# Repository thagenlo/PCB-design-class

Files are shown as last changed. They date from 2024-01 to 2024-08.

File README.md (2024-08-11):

# PCB-design-class
2.S975 KiCAD repo

**Multimeter Project**
multimeter 3D PCB 1
Screenshot 2024-08-11 at 10 22 29 AM
Screenshot 2024-08-11 at 10 22 42 AM
Screenshot 2024-08-11 at 10 22 52 AM
Screenshot 2024-08-11 at 10 23 01 AM
Screenshot 2024-08-11 at 10 23 08 AM

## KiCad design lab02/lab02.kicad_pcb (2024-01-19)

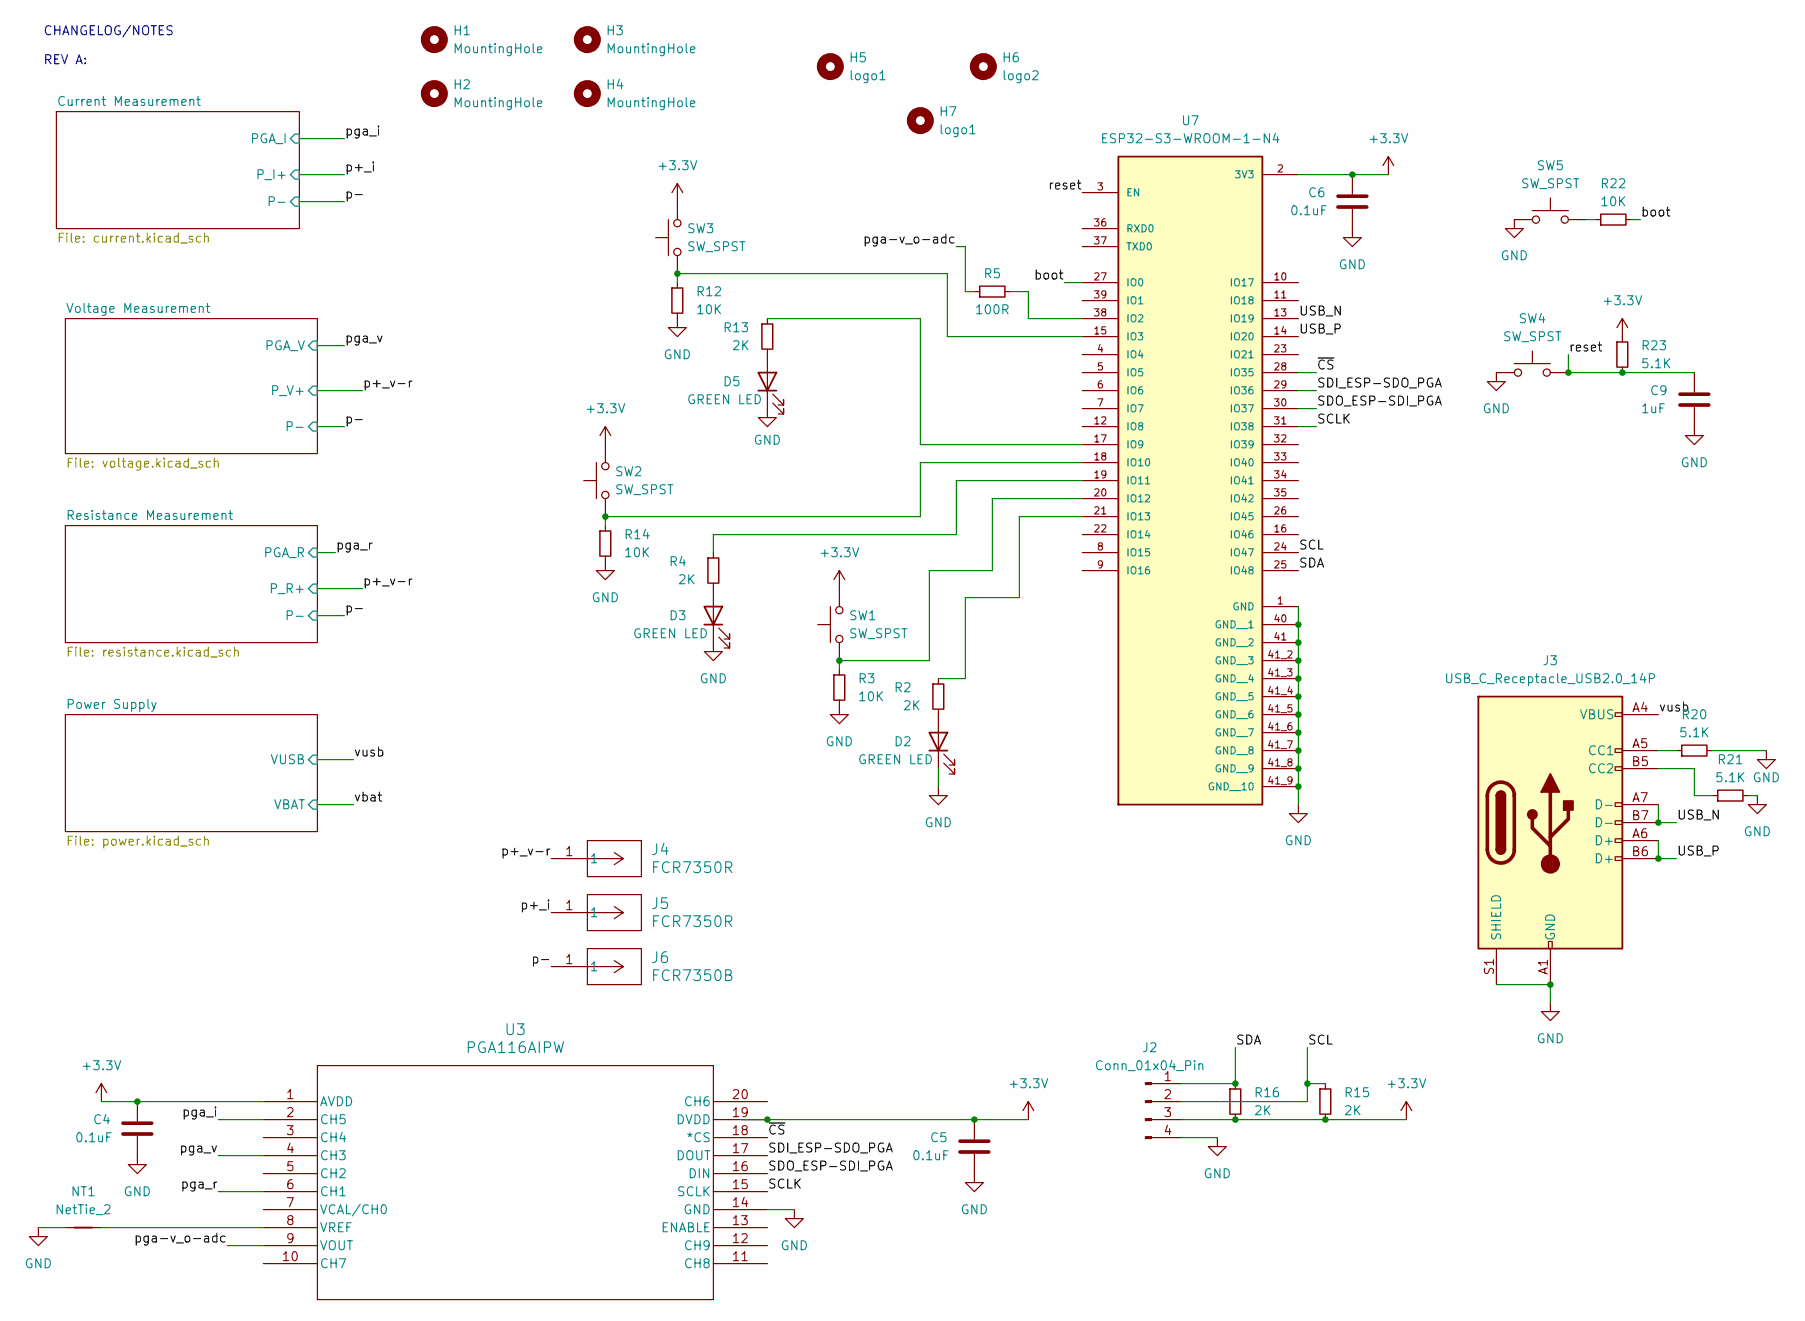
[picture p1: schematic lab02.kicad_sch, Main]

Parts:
C4, C5, C6: 0.1uF; C_0603_1608Metric
C9: 1uF; C_0603_1608Metric
D2, D3, D5: GREEN LED; LED_0603_1608Metric_Pad1.05x0.95mm_HandSolder; MPN LTST-C190GKT; Digikey PN 160-1183-1-ND
H1, H2, H3, H4: MountingHole; MountingHole_2.5mm
H5: logo1; EdgertonLogo
H6: logo2; EECSLogo
H7: logo1; MechE
J2: Conn_01x04_Pin; PPTC041LFBN-RC; MPN PPTC041LFBN-RC; Digikey PN S7002-ND
J3: USB_C_Receptacle_USB2.0_14P; USB_C_Receptacle_GCT_USB4085; MPN USB4085-GF-A; Digikey PN 2073-USB4085-GF-ACT-ND
J4, J5: FCR7350R; CONN1_FCR7350R_CLF; MPN FCR7350R; Digikey PN 4654-FCR7350R-ND
J6: FCR7350B; CONN1_FCR7350R_CLF; MPN FCR7350B; Digikey PN 4654-FCR7350B-ND
NT1: NetTie_2; NetTie-2_SMD_Pad0.5mm
R2, R4, R13, R15, R16: 2K; R_0603_1608Metric
R3, R12, R14, R22: 10K; R_0603_1608Metric
R5: 100R; R_0603_1608Metric
R20, R21, R23: 5.1K; R_0603_1608Metric
SW1, SW2, SW3, SW4, SW5: SW_SPST; SWITCH_FSMSM_TYC; MPN FSMSM; Digikey PN 450-1140-ND
U3: PGA116AIPW; PGA116AIPWR; MPN PGA116AIPWR; Digikey PN 296-23772-1-ND
U7: ESP32-S3-WROOM-1-N4; ESP32-S3-WROOM-1; PARTREV v1.0; Digikey PN 1965-ESP32-S3-WROOM-1-N4CT-ND

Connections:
+3.3V: C4.1, C5.1, C6.1, J2.3, R15.2, R16.2, R23.1, SW1.2, SW2.2, SW3.2, U3.1 (AVDD), U3.19 (DVDD), U7.2 (3V3); also elsewhere on the board
/SCL: J2.2, R15.1, U7.24 (IO47)
/SCLK: U3.15 (SCLK), U7.31 (IO38)
/SDA: J2.1, R16.1, U7.25 (IO48)
/SDI_ESP-SDO_PGA: U3.17 (DOUT), U7.29 (IO36)
/SDO_ESP-SDI_PGA: U3.16 (DIN), U7.30 (IO37)
/USB_N: J3.A7 (D-), J3.B7 (D-), U7.13 (IO19)
/USB_P: J3.A6 (D+), J3.B6 (D+), U7.14 (IO20)
/boot: R22.2, U7.27 (IO0)
/p+_i: J5.1; also elsewhere on the board
/p+_v-r: J4.1; also elsewhere on the board
/pga-v_o-adc: R5.1, U3.9 (VOUT)
/pga_i: U3.2 (CH5); also elsewhere on the board
/pga_r: U3.6 (CH1); also elsewhere on the board
/pga_v: U3.4 (CH3); also elsewhere on the board
/reset: C9.1, R23.2, SW4.2, U7.3 (EN)
/vusb: J3.A4 (VBUS), J3.A9 (VBUS), J3.B4 (VBUS), J3.B9 (VBUS); also elsewhere on the board
/~CS: U3.18 (*CS), U7.28 (IO35)
GND: C4.2, C5.2, C6.2, C9.2, D2.1 (K), D3.1 (K), D5.1 (K), J2.4, J3.A1 (GND), J3.A12 (GND), J3.B1 (GND), J3.B12 (GND), J3.S1 (SHIELD), J6.1, NT1.1, R3.2, R12.2, R14.2, R20.2, R21.2, SW4.1, SW5.1, U3.14 (GND), U7.1 (GND), U7.40 (GND__1), U7.41 (GND__2), U7.41_2 (GND__3), U7.41_3 (GND__4), U7.41_4 (GND__5), U7.41_5 (GND__6), U7.41_6 (GND__7), U7.41_7 (GND__8), U7.41_8 (GND__9), U7.41_9 (GND__10); also elsewhere on the board
unnamed: D2.2 (A), R2.2
unnamed: D3.2 (A), R4.2
unnamed: D5.2 (A), R13.2
unnamed: J3.A5 (CC1), R20.1
unnamed: J3.B5 (CC2), R21.1
unnamed: R22.1, SW5.2
unnamed: NT1.2, U3.8 (VREF)
unnamed: R5.2, U7.38 (IO2)
unnamed: R12.1, SW3.1, U7.15 (IO3)
unnamed: R13.1, U7.17 (IO9)
unnamed: R14.1, SW2.1, U7.18 (IO10)
unnamed: R4.1, U7.19 (IO11)
unnamed: R3.1, SW1.1, U7.20 (IO12)
unnamed: R2.1, U7.21 (IO13)

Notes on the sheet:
CHANGELOG/NOTES REV A:

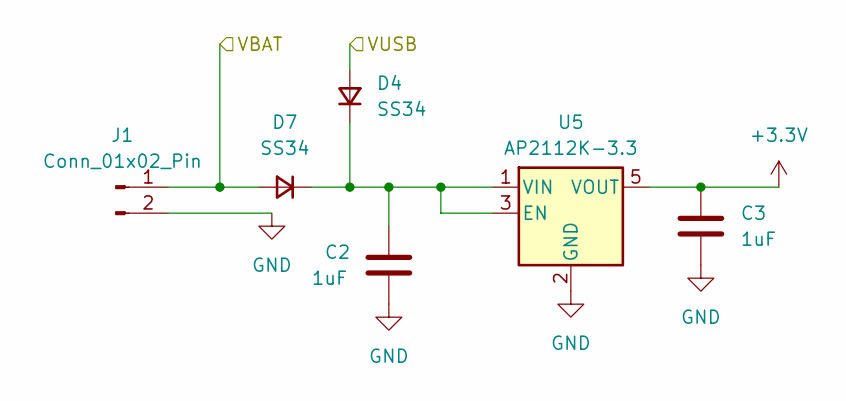
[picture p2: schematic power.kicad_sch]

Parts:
C2, C3: 1uF; C_0603_1608Metric
D4, D7: SS34; D_SMC
J1: Conn_01x02_Pin; JST_B2B-XH-A; MPN B2B-XH-A; Digikey PN 455-B2B-XH-A-ND
U5: AP2112K-3.3; SOT-23-5; MPN AP2112K-3.3TRG1; Digikey PN AP2112K-3.3TRG1DICT-ND

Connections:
+3.3V: C3.1, U5.5 (VOUT); also elsewhere on the board
/vbat: D7.2 (A), J1.1
/vusb: D4.2 (A); also elsewhere on the board
GND: C2.2, C3.2, J1.2, U5.2 (GND); also elsewhere on the board
unnamed: C2.1, D4.1 (K), D7.1 (K), U5.1 (VIN), U5.3 (EN)

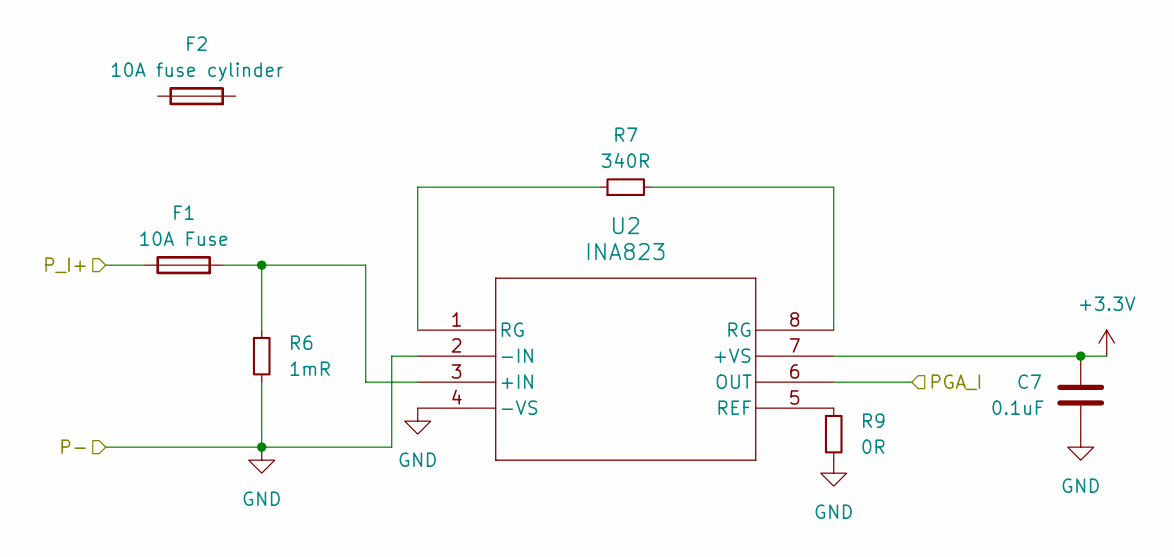
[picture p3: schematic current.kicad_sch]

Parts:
C7: 0.1uF; C_0603_1608Metric
F1: 10A Fuse; FUSE_31.8221_SCH; MPN 0031.8221; Digikey PN 486-1260-ND
F2: 10A fuse cylinder; MPN 7010.3530; Digikey PN 486-1865-ND
R6: 1mR; CSNL1206FT1L00; MPN CSNL1206FT1L00; Digikey PN CSNL1206FT1L00CT-ND
R7: 340R; R_0603_1608Metric
R9: 0R; R_0603_1608Metric
U2: INA823; SOIC-8_3.9x4.9mm_P1.27mm; MPN INA823DT; Digikey PN 296-INA823DTCT-ND

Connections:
+3.3V: C7.1, U2.7 (+VS); also elsewhere on the board
/p+_i: F1.1; also elsewhere on the board
/pga_i: U2.6 (OUT); also elsewhere on the board
GND: C7.2, R6.2, R9.2, U2.2 (-IN), U2.4 (-VS); also elsewhere on the board
unnamed: R7.1, U2.1 (RG)
unnamed: R7.2, U2.8 (RG)
unnamed: F1.2, R6.1, U2.3 (+IN)
unnamed: R9.1, U2.5 (REF)

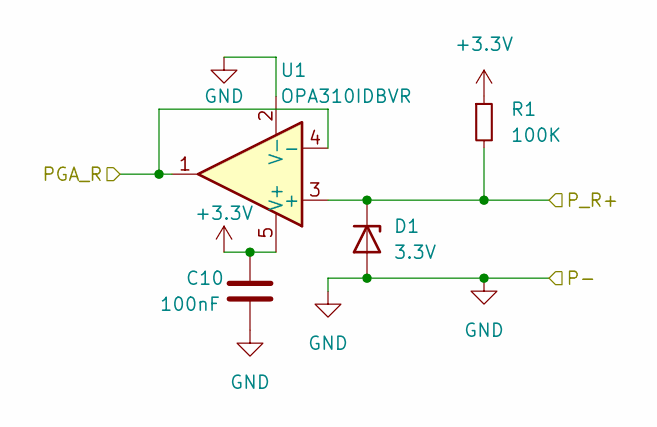
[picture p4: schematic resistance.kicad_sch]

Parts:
C10: 100nF; C_0603_1608Metric
D1: 3.3V; MMSZ4684T1G; MPN MMSZ4684T1G; Digikey PN MMSZ4684T1GOSCT-ND
R1: 100K; R_0603_1608Metric
U1: OPA310IDBVR; MPN OPA310IDBVR; Digikey PN 296-OPA310IDBVRCT-ND

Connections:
+3.3V: C10.1, R1.1, U1.5 (V+); also elsewhere on the board
/p+_v-r: D1.1 (K), R1.2, U1.3 (+); also elsewhere on the board
/pga_r: U1.1, U1.4 (-); also elsewhere on the board
GND: C10.2, D1.2 (A), U1.2 (V-); also elsewhere on the board

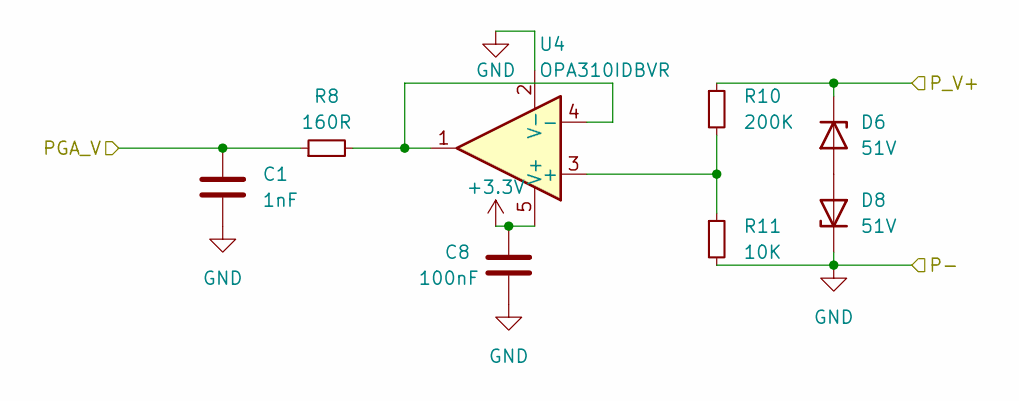
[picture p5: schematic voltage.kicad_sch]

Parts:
C1: 1nF; C_0603_1608Metric
C8: 100nF; C_0603_1608Metric
D6, D8: 51V; BZT52C51-7-F; MPN BZT52C51-7-F; Digikey PN BZT52C51-FDICT-ND
R8: 160R; R_0603_1608Metric
R10: 200K; R_0603_1608Metric
R11: 10K; R_0603_1608Metric
U4: OPA310IDBVR; MPN OPA310IDBVR; Digikey PN 296-OPA310IDBVRCT-ND

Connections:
+3.3V: C8.1, U4.5 (V+); also elsewhere on the board
/p+_v-r: D6.1 (K), R10.1; also elsewhere on the board
/pga_v: C1.1, R8.1; also elsewhere on the board
GND: C1.2, C8.2, D8.1 (K), R11.2, U4.2 (V-); also elsewhere on the board
unnamed: D6.2 (A), D8.2 (A)
unnamed: R10.2, R11.1, U4.3 (+)
unnamed: R8.2, U4.1, U4.4 (-)

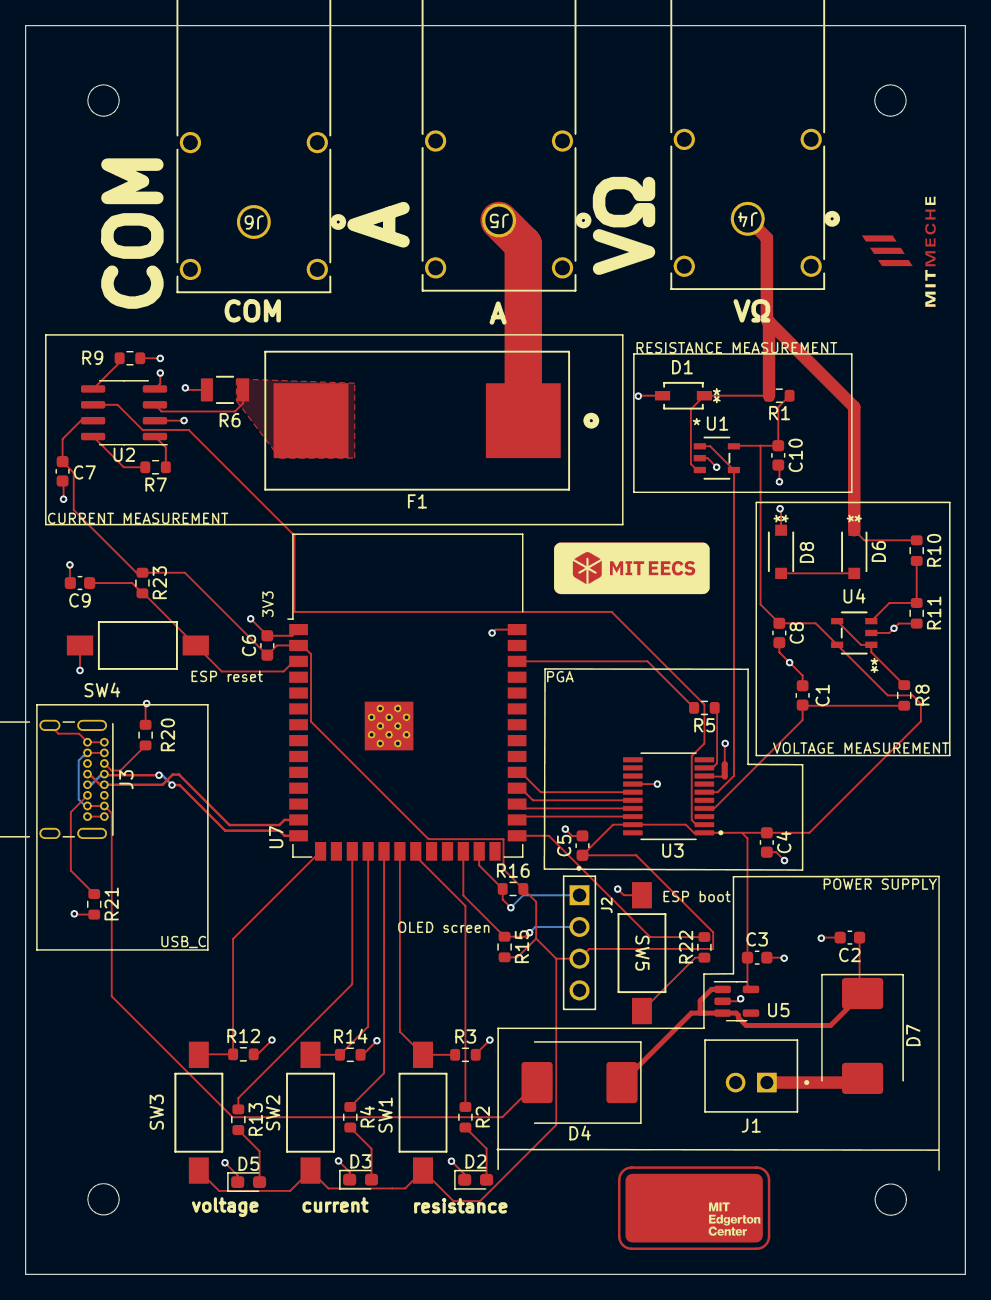
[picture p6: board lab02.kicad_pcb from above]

Board: 2 copper layers, 75.3 x 100.0 mm, 64 parts (0 on the bottom side), 42 nets.

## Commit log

2024-01-11 set up
    [current.kicad_sch, lab02.kicad_pcb, lab02.kicad_sch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]
2024-01-11 main v0
    [lab02.kicad_sch, resistance.kicad_sch]
2024-01-18 pcb layout v0
    [current.kicad_sch, lab02.kicad_pcb, lab02.kicad_sch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]
2024-01-18 pcb layout v1
    [lab02.kicad_pcb]
2024-01-19 v7 pcb
    [lab02.kicad_pcb, lab02.kicad_sch, power.kicad_sch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]
